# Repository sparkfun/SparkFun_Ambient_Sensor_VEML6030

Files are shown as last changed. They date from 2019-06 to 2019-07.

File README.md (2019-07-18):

SparkFun Ambient Light Sensor VEML6030 (Qwiic) 
========================================

SparkFun Ambient Light Sensor

[*SparkFun Ambient LIght Sensor - VEML6030 (Qwiic) (SEN-15436)*](https://www.sparkfun.com/products/15436)

The SparkFun Ambient Light Sensor - VEML6030 (Qwiic) is an I<sup>2</sup>C enabled
ambient light sensor with high sensitivity and high accuracy. It reads ambient
light in Lux and boasts a number of nice features including: the ability to set
high and low thresholds for an optional interrupt, power saving features that enable
single digit micro-amp current draw, and a readable  range from zero to 120,000 Lux. We've also written an Arduino 
library that gives full access to all features and includes example code demonstrating all its' abilities (see link below under **Documentation**). 

Repository Contents
-------------------

* **/Documentation** - Data sheets, additional product information
* **/Hardware** - Eagle design files (.brd, .sch)
* **/Libraries** - Libraries for use with the SparkFun Ambient Light Sensor.
* **/Production** - Production panel files (.brd)

Documentation
--------------
* **[SparkFun Ambient Light Sensor Arduino Library](https://github.com/sparkfun/SparkFun_Ambient_Light_Sensor_Arduino_Library)** - Arduino Library
* **[Hookup Guide](https://learn.sparkfun.com/tutorials/qwiic-ambient-light-sensor-veml6030-hookup-guide)** - Basic hookup guide for the SparkFun Ambient Light Sensor
* **[Qwiic Ecosystem](https://www.sparkfun.com/qwiic)** - Qwiic enabled for fast prototyping!

License Information
-------------------

This product is _**open source**_! 

Please review the LICENSE.md file for license information. 

If you have any questions or concerns on licensing, please contact technical support on our [SparkFun forums](https://forum.sparkfun.com/viewforum.php?f=152).

Distributed as-is; no warranty is given.

- Your friends at SparkFun.

_<COLLABORATION CREDIT>_

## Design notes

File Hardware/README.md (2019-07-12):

SparkFun Ambient Light Sensor VEML6030 Design Files
=====================================

The .sch and .brd files hare are Eagle CAD schematic and PCB design files from SparkFun Electronics.
A freeware version of Eagle can be found [here](http://www.cadsoftusa.com/download-eagle/freeware/).

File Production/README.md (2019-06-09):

SparkFun <PRODUCT NAME> Production Files
=========================================

These are the production files SparkFun uses for printing PCBs.

License Information
-------------------
This product is open source! 

The hardware is released under [Creative Commons ShareAlike 4.0 International](https://creativecommons.org/licenses/by-sa/4.0/).

Please use, reuse, and modify these files as you see fit. Please maintain attribution to SparkFun Electronics and release anything derivative under the same license.

Distributed as-is; no warranty is given.

- Your friends at SparkFun.

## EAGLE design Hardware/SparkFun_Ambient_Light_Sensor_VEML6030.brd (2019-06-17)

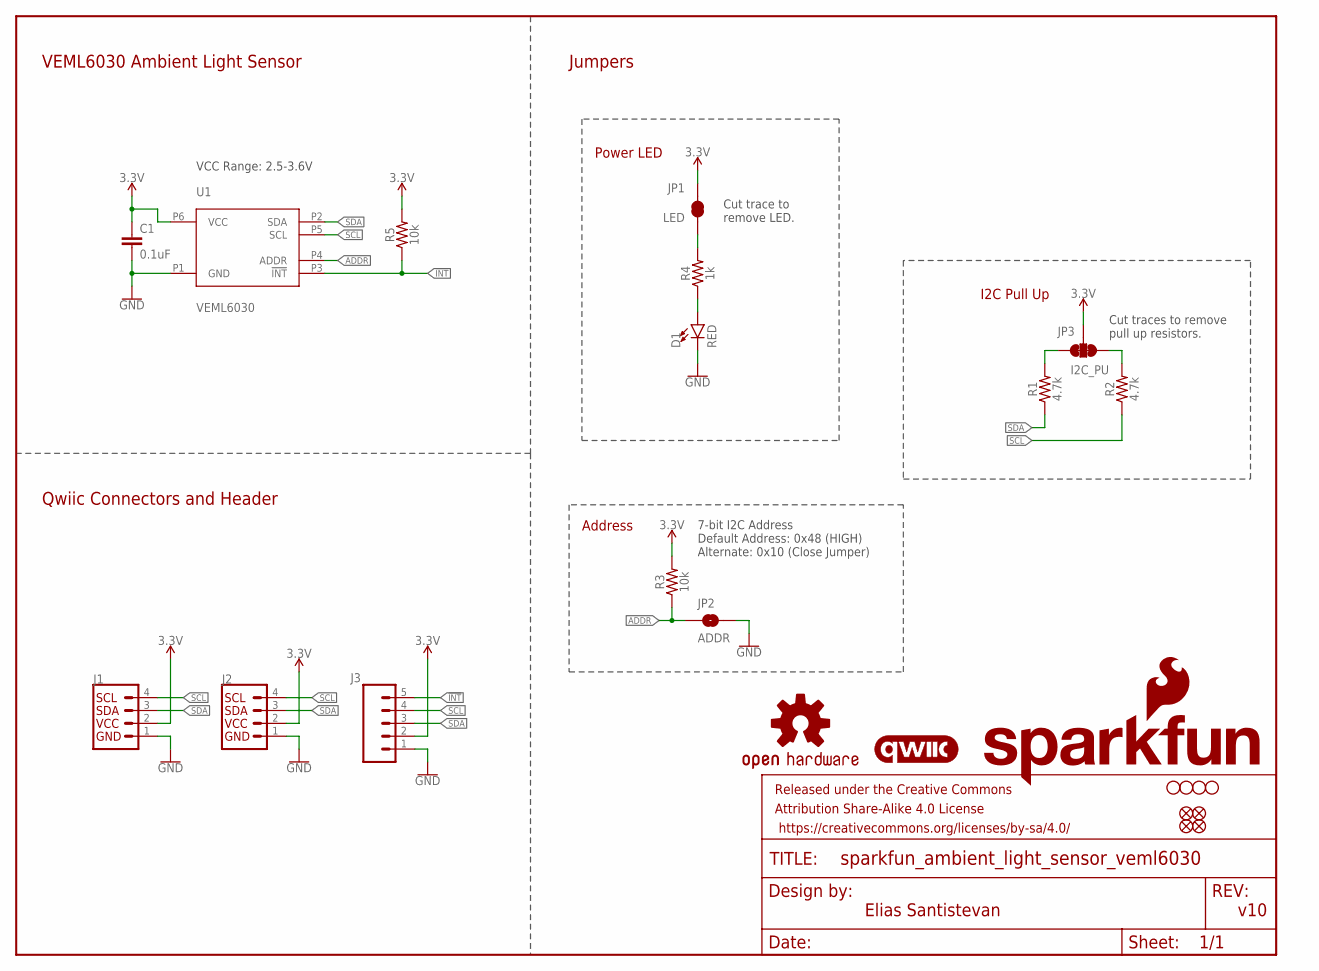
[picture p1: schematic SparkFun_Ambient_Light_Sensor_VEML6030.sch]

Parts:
C1: 0.1uF; 0603
D1: RED; LED-0603
FD1, FD2, FD3, FD4: FIDUCIAL1X2; FIDUCIAL-1X2
FRAME1: FRAME-LETTER; CREATIVE_COMMONS
H1, H2, H3, H4: STAND-OFFTIGHT; STAND-OFF-TIGHT
J1, J2: QWIIC_CONNECTORJS-1MM; JST04_1MM_RA
J3: CONN_05NO_SILK; 1X05_NO_SILK
JP1: LED; SMT-JUMPER_2_NC_TRACE_SILK
JP2: ADDR; SMT-JUMPER_2_NO_SILK
JP3: I2C_PU; SMT-JUMPER_3_2-NC_TRACE_SILK
LOGO1: SFE_LOGO_NAME_FLAME.1_INCH; SFE_LOGO_NAME_FLAME_.1
LOGO2: OSHW-LOGOS; OSHW-LOGO-S
R1, R2: 4.7k; 0603
R3, R5: 10k; 0603
R4: 1k; 0603
U1: VEML6030
U$1: QWIIC_LOGO_5MM; QWIIC_5MM

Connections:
3.3V: C1.1, J1.2, J2.2, J3.2, JP1.2, JP3.2, R3.2, R5.2, U1.P6 (VCC)
!INT: J3.5, R5.1, U1.P3 (!INT)
ADDR: JP2.1, R3.1, U1.P4 (ADDR)
GND: C1.2, D1.C, J1.1, J2.1, J3.1, JP2.2, U1.P1 (GND)
unnamed: D1.A, R4.1
unnamed: JP1.1, R4.2
unnamed: JP3.3, R1.2
unnamed: JP3.1, R2.2
SCL: J1.4, J2.4, J3.4, R2.1, U1.P5 (SCL)
SDA: J1.3, J2.3, J3.3, R1.1, U1.P2 (SDA)

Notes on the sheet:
v10
Elias Santistevan
Qwiic Connectors and Header
VEML6030 Ambient Light Sensor
Jumpers
Power LED
I2C Pull Up
Address
7-bit I2C Address Default Address: 0x48 (HIGH) Alternate: 0x10 (Close Jumper)
Cut trace to remove LED.
Cut traces to remove pull up resistors.
VCC Range: 2.5-3.6V

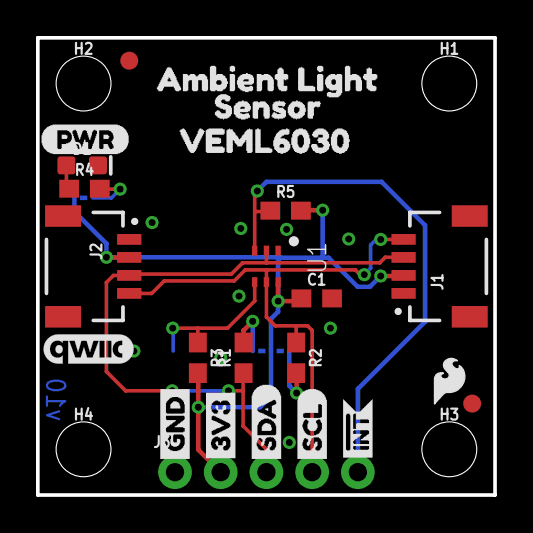
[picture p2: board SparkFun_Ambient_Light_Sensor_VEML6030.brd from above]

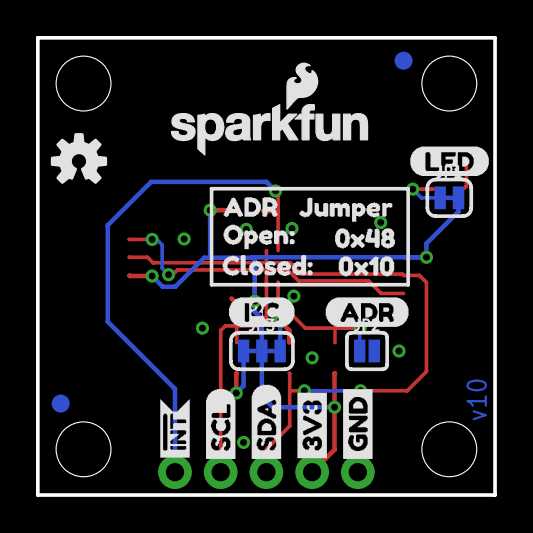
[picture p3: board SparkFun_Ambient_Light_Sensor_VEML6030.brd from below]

Board: 2 copper layers, 25.4 x 25.4 mm, 50 parts (21 on the bottom side), 10 nets.

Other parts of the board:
U$2, U$11: 3V3-04
U$3, U$8: GND-04
U$4, U$9: SDA-[)
U$5, U$10: SCL-[)
U$6, U$7: INT#-[<
U$12: I_SUPER2_C-()-04
U$13: ADR-()
U$14: LED0
U$15: AMBIENT_LIGHT0
U$16: SENSOR1
U$17: VEML60302
U$18: SFE_LOGO_FLAME_.1
U$19: PWR-()-04
U$20: CLOSED#2
U$21: OPEN#0
U$22: 0X481
U$24: 0X103
U$25: ADR0
U$26: JUMPER1

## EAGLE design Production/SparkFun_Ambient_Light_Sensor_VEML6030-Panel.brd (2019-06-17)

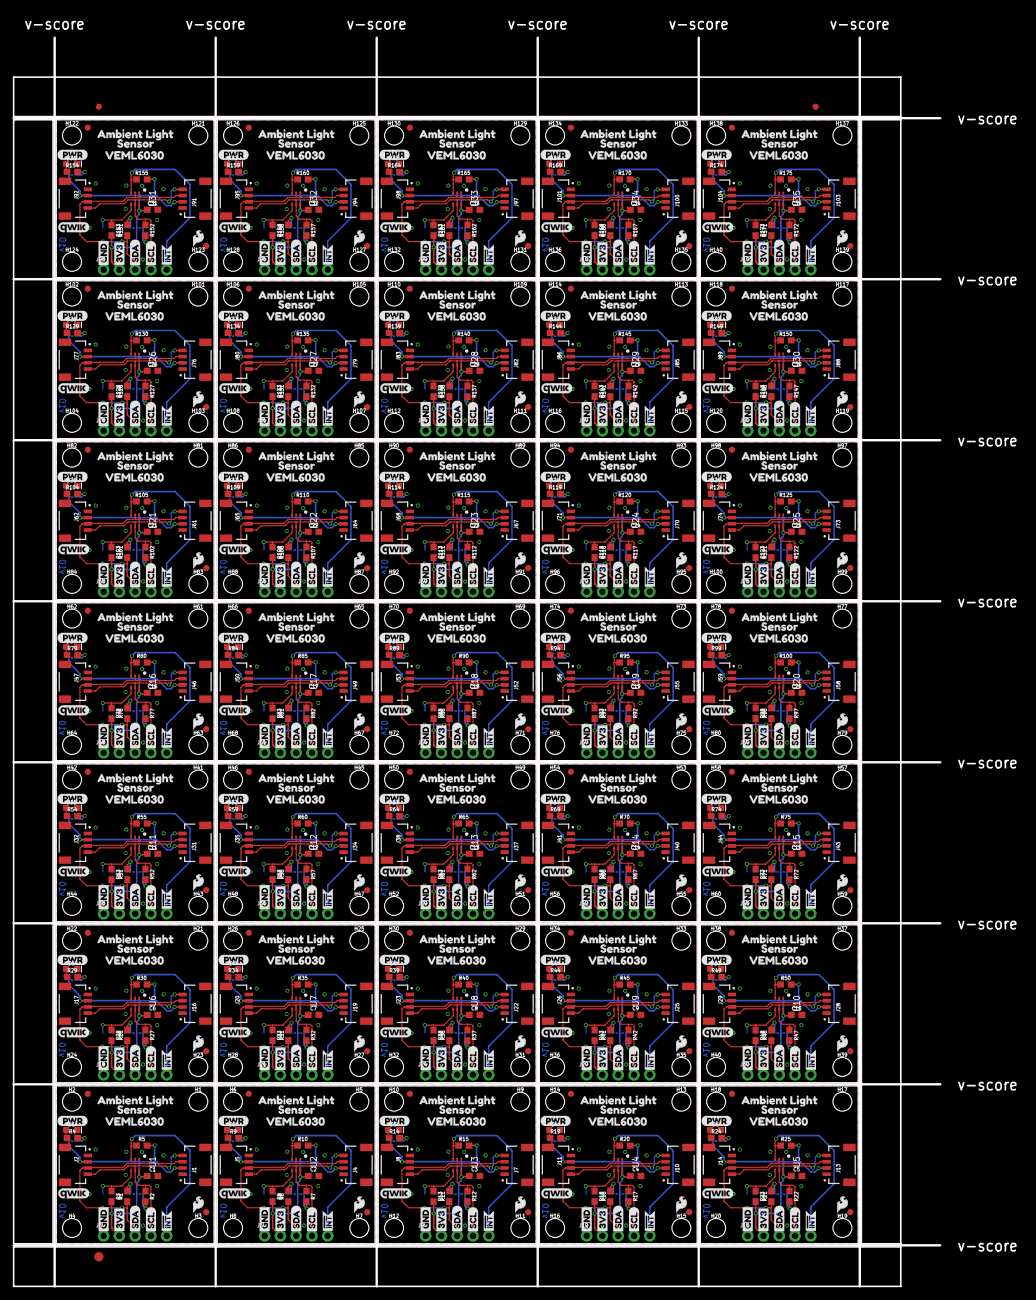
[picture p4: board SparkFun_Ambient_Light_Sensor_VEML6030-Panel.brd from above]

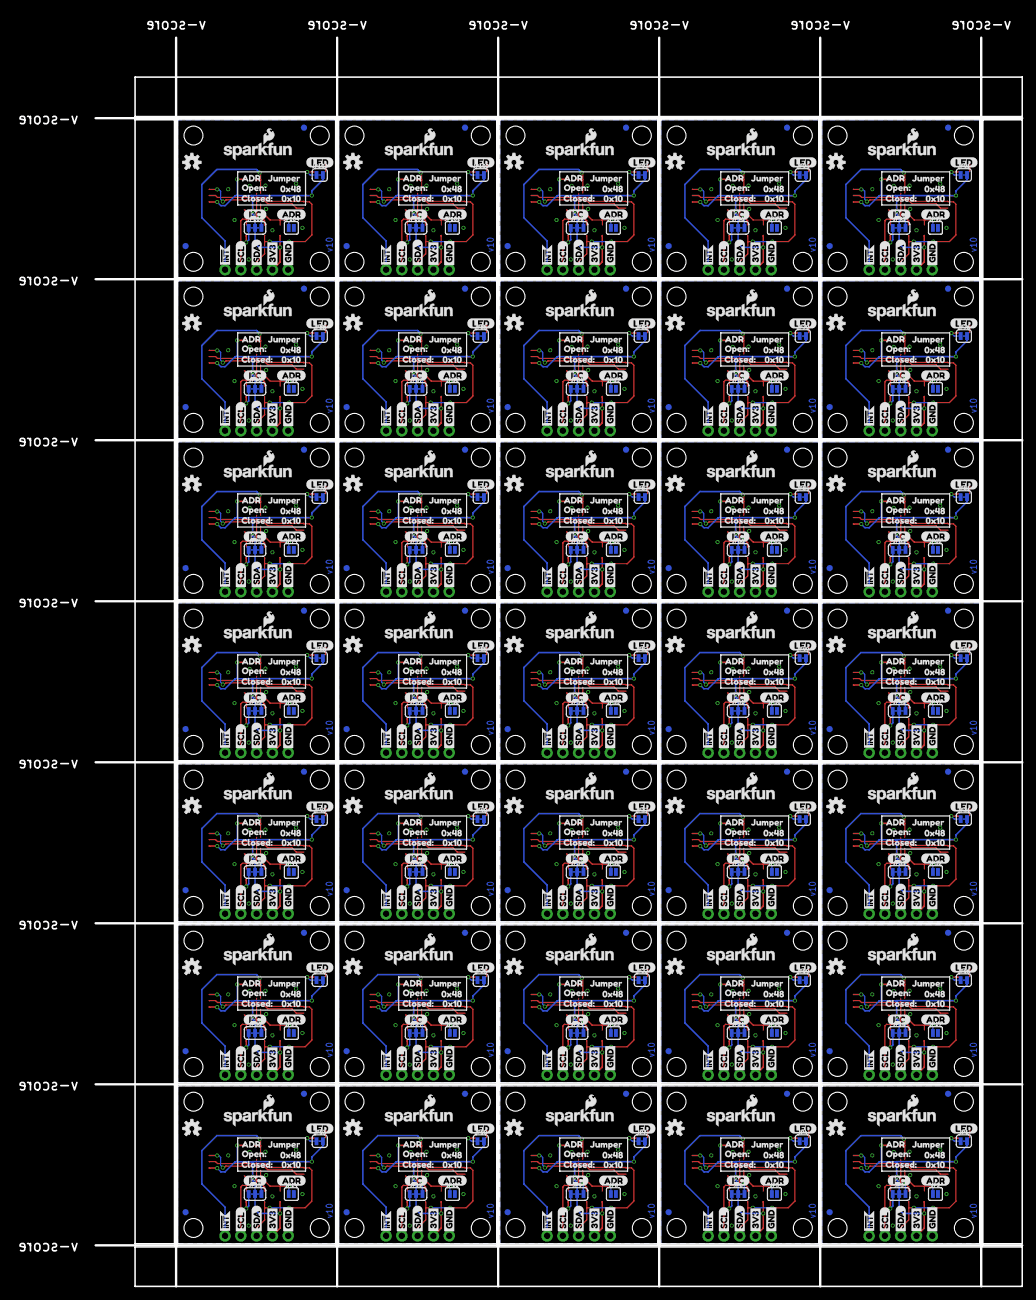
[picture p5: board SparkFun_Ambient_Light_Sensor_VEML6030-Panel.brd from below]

Board: 2 copper layers, 149.1 x 200.9 mm, 1718 parts (735 on the bottom side), 350 nets.

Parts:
C1, C2, C3, C4, C5, C6, C7, C8, C9, C10, C11, C12, C13, C14, C15, C16, C17, C18, C19, C20, C21, C22, C23, C24, C25, C26, C27, C28, C29, C30, C31, C32, C33, C34, C35: 0.1uF; 0603
D1, D2, D3, D4, D5, D6, D7, D8, D9, D10, D11, D12, D13, D14, D15, D16, D17, D18, D19, D20, D21, D22, D23, D24, D25, D26, D27, D28, D29, D30, D31, D32, D33, D34, D35: RED; LED-0603
E$1, E$2: FIDUCIAL-1X2
E$3: FIDUCIAL-1.5X3
FD1, FD2, FD3, FD4, FD5, FD6, FD7, FD8, FD9, FD10, FD11, FD12, FD13, FD14, FD15, FD16, FD17, FD18, FD19, FD20, FD21, FD22, FD23, FD24, FD25, FD26, FD27, FD28, FD29, FD30, FD31, FD32, FD33, FD34, FD35, FD36, FD37, FD38, FD39, FD40, FD41, FD42, FD43, FD44, FD45, FD46, FD47, FD48, FD49, FD50, FD51, FD52, FD53, FD54, FD55, FD56, FD57, FD58, FD59, FD60, FD61, FD62, FD63, FD64, FD65, FD66, FD67, FD68, FD69, FD70, FD71, FD72, FD73, FD74, FD75, FD76, FD77, FD78, FD79, FD80, FD81, FD82, FD83, FD84, FD85, FD86, FD87, FD88, FD89, FD90, FD91, FD92, FD93, FD94, FD95, FD96, FD97, FD98, FD99, FD100, FD101, FD102, FD103, FD104, FD105, FD106, FD107, FD108, FD109, FD110, FD111, FD112, FD113, FD114, FD115, FD116, FD117, FD118, FD119, FD120, FD121, FD122, FD123, FD124, FD125, FD126, FD127, FD128, FD129, FD130, FD131, FD132, FD133, FD134, FD135, FD136, FD137, FD138, FD139, FD140: FIDUCIAL1X2; FIDUCIAL-1X2
H1, H2, H3, H4, H5, H6, H7, H8, H9, H10, H11, H12, H13, H14, H15, H16, H17, H18, H19, H20, H21, H22, H23, H24, H25, H26, H27, H28, H29, H30, H31, H32, H33, H34, H35, H36, H37, H38, H39, H40, H41, H42, H43, H44, H45, H46, H47, H48, H49, H50, H51, H52, H53, H54, H55, H56, H57, H58, H59, H60, H61, H62, H63, H64, H65, H66, H67, H68, H69, H70, H71, H72, H73, H74, H75, H76, H77, H78, H79, H80, H81, H82, H83, H84, H85, H86, H87, H88, H89, H90, H91, H92, H93, H94, H95, H96, H97, H98, H99, H100, H101, H102, H103, H104, H105, H106, H107, H108, H109, H110, H111, H112, H113, H114, H115, H116, H117, H118, H119, H120, H121, H122, H123, H124, H125, H126, H127, H128, H129, H130, H131, H132, H133, H134, H135, H136, H137, H138, H139, H140: STAND-OFFTIGHT; STAND-OFF-TIGHT
J1, J2, J4, J5, J7, J8, J10, J11, J13, J14, J16, J17, J19, J20, J22, J23, J25, J26, J28, J29, J31, J32, J34, J35, J37, J38, J40, J41, J43, J44, J46, J47, J49, J50, J52, J53, J55, J56, J58, J59, J61, J62, J64, J65, J67, J68, J70, J71, J73, J74, J76, J77, J79, J80, J82, J83, J85, J86, J88, J89, J91, J92, J94, J95, J97, J98, J100, J101, J103, J104: JST04_1MM_RA
J3, J6, J9, J12, J15, J18, J21, J24, J27, J30, J33, J36, J39, J42, J45, J48, J51, J54, J57, J60, J63, J66, J69, J72, J75, J78, J81, J84, J87, J90, J93, J96, J99, J102, J105: 1X05_NO_SILK
JP1, JP4, JP7, JP10, JP13, JP16, JP19, JP22, JP25, JP28, JP31, JP34, JP37, JP40, JP43, JP46, JP49, JP52, JP55, JP58, JP61, JP64, JP67, JP70, JP73, JP76, JP79, JP82, JP85, JP88, JP91, JP94, JP97, JP100, JP103: LED; SMT-JUMPER_2_NC_TRACE_SILK
JP2, JP5, JP8, JP11, JP14, JP17, JP20, JP23, JP26, JP29, JP32, JP35, JP38, JP41, JP44, JP47, JP50, JP53, JP56, JP59, JP62, JP65, JP68, JP71, JP74, JP77, JP80, JP83, JP86, JP89, JP92, JP95, JP98, JP101, JP104: ADDR; SMT-JUMPER_2_NO_SILK
JP3, JP6, JP9, JP12, JP15, JP18, JP21, JP24, JP27, JP30, JP33, JP36, JP39, JP42, JP45, JP48, JP51, JP54, JP57, JP60, JP63, JP66, JP69, JP72, JP75, JP78, JP81, JP84, JP87, JP90, JP93, JP96, JP99, JP102, JP105: I2C_PU; SMT-JUMPER_3_2-NC_TRACE_SILK
LOGO1, LOGO3, LOGO5, LOGO7, LOGO9, LOGO11, LOGO13, LOGO15, LOGO17, LOGO19, LOGO21, LOGO23, LOGO25, LOGO27, LOGO29, LOGO31, LOGO33, LOGO35, LOGO37, LOGO39, LOGO41, LOGO43, LOGO45, LOGO47, LOGO49, LOGO51, LOGO53, LOGO55, LOGO57, LOGO59, LOGO61, LOGO63, LOGO65, LOGO67, LOGO69: SFE_LOGO_NAME_FLAME.1_INCH; SFE_LOGO_NAME_FLAME_.1
LOGO2, LOGO4, LOGO6, LOGO8, LOGO10, LOGO12, LOGO14, LOGO16, LOGO18, LOGO20, LOGO22, LOGO24, LOGO26, LOGO28, LOGO30, LOGO32, LOGO34, LOGO36, LOGO38, LOGO40, LOGO42, LOGO44, LOGO46, LOGO48, LOGO50, LOGO52, LOGO54, LOGO56, LOGO58, LOGO60, LOGO62, LOGO64, LOGO66, LOGO68, LOGO70: OSHW-LOGOS; OSHW-LOGO-S
R1, R2, R6, R7, R11, R12, R16, R17, R21, R22, R26, R27, R31, R32, R36, R37, R41, R42, R46, R47, R51, R52, R56, R57, R61, R62, R66, R67, R71, R72, R76, R77, R81, R82, R86, R87, R91, R92, R96, R97, R101, R102, R106, R107, R111, R112, R116, R117, R121, R122, R126, R127, R131, R132, R136, R137, R141, R142, R146, R147, R151, R152, R156, R157, R161, R162, R166, R167, R171, R172: 4.7k; 0603
R3, R5, R8, R10, R13, R15, R18, R20, R23, R25, R28, R30, R33, R35, R38, R40, R43, R45, R48, R50, R53, R55, R58, R60, R63, R65, R68, R70, R73, R75, R78, R80, R83, R85, R88, R90, R93, R95, R98, R100, R103, R105, R108, R110, R113, R115, R118, R120, R123, R125, R128, R130, R133, R135, R138, R140, R143, R145, R148, R150, R153, R155, R158, R160, R163, R165, R168, R170, R173, R175: 10k; 0603
R4, R9, R14, R19, R24, R29, R34, R39, R44, R49, R54, R59, R64, R69, R74, R79, R84, R89, R94, R99, R104, R109, R114, R119, R124, R129, R134, R139, R144, R149, R154, R159, R164, R169, R174: 1k; 0603
U1, U2, U3, U4, U5, U6, U7, U8, U9, U10, U11, U12, U13, U14, U15, U16, U17, U18, U19, U20, U21, U22, U23, U24, U25, U26, U27, U28, U29, U30, U31, U32, U33, U34, U35: VEML6030
U$1, U$23, U$51, U$76, U$101, U$126, U$151, U$176, U$201, U$226, U$251, U$276, U$301, U$326, U$351, U$376, U$401, U$426, U$451, U$476, U$501, U$526, U$551, U$576, U$601, U$626, U$651, U$676, U$701, U$726, U$751, U$776, U$801, U$826, U$851: QWIIC_LOGO_5MM; QWIIC_5MM
U$2, U$11, U$27, U$36, U$52, U$61, U$77, U$86, U$102, U$111, U$127, U$136, U$152, U$161, U$177, U$186, U$202, U$211, U$227, U$236, U$252, U$261, U$277, U$286, U$302, U$311, U$327, U$336, U$352, U$361, U$377, U$386, U$402, U$411, U$427, U$436, U$452, U$461, U$477, U$486, U$502, U$511, U$527, U$536, U$552, U$561, U$577, U$586, U$602, U$611, U$627, U$636, U$652, U$661, U$677, U$686, U$702, U$711, U$727, U$736, U$752, U$761, U$777, U$786, U$802, U$811, U$827, U$836, U$852, U$861: 3V3-04
U$3, U$8, U$28, U$33, U$53, U$58, U$78, U$83, U$103, U$108, U$128, U$133, U$153, U$158, U$178, U$183, U$203, U$208, U$228, U$233, U$253, U$258, U$278, U$283, U$303, U$308, U$328, U$333, U$353, U$358, U$378, U$383, U$403, U$408, U$428, U$433, U$453, U$458, U$478, U$483, U$503, U$508, U$528, U$533, U$553, U$558, U$578, U$583, U$603, U$608, U$628, U$633, U$653, U$658, U$678, U$683, U$703, U$708, U$728, U$733, U$753, U$758, U$778, U$783, U$803, U$808, U$828, U$833, U$853, U$858: GND-04
U$4, U$9, U$29, U$34, U$54, U$59, U$79, U$84, U$104, U$109, U$129, U$134, U$154, U$159, U$179, U$184, U$204, U$209, U$229, U$234, U$254, U$259, U$279, U$284, U$304, U$309, U$329, U$334, U$354, U$359, U$379, U$384, U$404, U$409, U$429, U$434, U$454, U$459, U$479, U$484, U$504, U$509, U$529, U$534, U$554, U$559, U$579, U$584, U$604, U$609, U$629, U$634, U$654, U$659, U$679, U$684, U$704, U$709, U$729, U$734, U$754, U$759, U$779, U$784, U$804, U$809, U$829, U$834, U$854, U$859: SDA-[)
U$5, U$10, U$30, U$35, U$55, U$60, U$80, U$85, U$105, U$110, U$130, U$135, U$155, U$160, U$180, U$185, U$205, U$210, U$230, U$235, U$255, U$260, U$280, U$285, U$305, U$310, U$330, U$335, U$355, U$360, U$380, U$385, U$405, U$410, U$430, U$435, U$455, U$460, U$480, U$485, U$505, U$510, U$530, U$535, U$555, U$560, U$580, U$585, U$605, U$610, U$630, U$635, U$655, U$660, U$680, U$685, U$705, U$710, U$730, U$735, U$755, U$760, U$780, U$785, U$805, U$810, U$830, U$835, U$855, U$860: SCL-[)
U$6, U$7, U$31, U$32, U$56, U$57, U$81, U$82, U$106, U$107, U$131, U$132, U$156, U$157, U$181, U$182, U$206, U$207, U$231, U$232, U$256, U$257, U$281, U$282, U$306, U$307, U$331, U$332, U$356, U$357, U$381, U$382, U$406, U$407, U$431, U$432, U$456, U$457, U$481, U$482, U$506, U$507, U$531, U$532, U$556, U$557, U$581, U$582, U$606, U$607, U$631, U$632, U$656, U$657, U$681, U$682, U$706, U$707, U$731, U$732, U$756, U$757, U$781, U$782, U$806, U$807, U$831, U$832, U$856, U$857: INT#-[<
U$12, U$37, U$62, U$87, U$112, U$137, U$162, U$187, U$212, U$237, U$262, U$287, U$312, U$337, U$362, U$387, U$412, U$437, U$462, U$487, U$512, U$537, U$562, U$587, U$612, U$637, U$662, U$687, U$712, U$737, U$762, U$787, U$812, U$837, U$862: I_SUPER2_C-()-04
U$13, U$38, U$63, U$88, U$113, U$138, U$163, U$188, U$213, U$238, U$263, U$288, U$313, U$338, U$363, U$388, U$413, U$438, U$463, U$488, U$513, U$538, U$563, U$588, U$613, U$638, U$663, U$688, U$713, U$738, U$763, U$788, U$813, U$838, U$863: ADR-()
U$14, U$39, U$64, U$89, U$114, U$139, U$164, U$189, U$214, U$239, U$264, U$289, U$314, U$339, U$364, U$389, U$414, U$439, U$464, U$489, U$514, U$539, U$564, U$589, U$614, U$639, U$664, U$689, U$714, U$739, U$764, U$789, U$814, U$839, U$864: LED0
U$15, U$40, U$65, U$90, U$115, U$140, U$165, U$190, U$215, U$240, U$265, U$290, U$315, U$340, U$365, U$390, U$415, U$440, U$465, U$490, U$515, U$540, U$565, U$590, U$615, U$640, U$665, U$690, U$715, U$740, U$765, U$790, U$815, U$840, U$865: AMBIENT_LIGHT0
U$16, U$41, U$66, U$91, U$116, U$141, U$166, U$191, U$216, U$241, U$266, U$291, U$316, U$341, U$366, U$391, U$416, U$441, U$466, U$491, U$516, U$541, U$566, U$591, U$616, U$641, U$666, U$691, U$716, U$741, U$766, U$791, U$816, U$841, U$866: SENSOR1
U$17, U$42, U$67, U$92, U$117, U$142, U$167, U$192, U$217, U$242, U$267, U$292, U$317, U$342, U$367, U$392, U$417, U$442, U$467, U$492, U$517, U$542, U$567, U$592, U$617, U$642, U$667, U$692, U$717, U$742, U$767, U$792, U$817, U$842, U$867: VEML60302
U$18, U$43, U$68, U$93, U$118, U$143, U$168, U$193, U$218, U$243, U$268, U$293, U$318, U$343, U$368, U$393, U$418, U$443, U$468, U$493, U$518, U$543, U$568, U$593, U$618, U$643, U$668, U$693, U$718, U$743, U$768, U$793, U$818, U$843, U$868: SFE_LOGO_FLAME_.1
U$19, U$44, U$69, U$94, U$119, U$144, U$169, U$194, U$219, U$244, U$269, U$294, U$319, U$344, U$369, U$394, U$419, U$444, U$469, U$494, U$519, U$544, U$569, U$594, U$619, U$644, U$669, U$694, U$719, U$744, U$769, U$794, U$819, U$844, U$869: PWR-()-04
U$20, U$49, U$74, U$99, U$124, U$149, U$174, U$199, U$224, U$249, U$274, U$299, U$324, U$349, U$374, U$399, U$424, U$449, U$474, U$499, U$524, U$549, U$574, U$599, U$624, U$649, U$674, U$699, U$724, U$749, U$774, U$799, U$824, U$849, U$874: CLOSED#2
U$21, U$50, U$75, U$100, U$125, U$150, U$175, U$200, U$225, U$250, U$275, U$300, U$325, U$350, U$375, U$400, U$425, U$450, U$475, U$500, U$525, U$550, U$575, U$600, U$625, U$650, U$675, U$700, U$725, U$750, U$775, U$800, U$825, U$850, U$875: OPEN#0
U$22, U$45, U$70, U$95, U$120, U$145, U$170, U$195, U$220, U$245, U$270, U$295, U$320, U$345, U$370, U$395, U$420, U$445, U$470, U$495, U$520, U$545, U$570, U$595, U$620, U$645, U$670, U$695, U$720, U$745, U$770, U$795, U$820, U$845, U$870: 0X481
U$24, U$46, U$71, U$96, U$121, U$146, U$171, U$196, U$221, U$246, U$271, U$296, U$321, U$346, U$371, U$396, U$421, U$446, U$471, U$496, U$521, U$546, U$571, U$596, U$621, U$646, U$671, U$696, U$721, U$746, U$771, U$796, U$821, U$846, U$871: 0X103
U$25, U$47, U$72, U$97, U$122, U$147, U$172, U$197, U$222, U$247, U$272, U$297, U$322, U$347, U$372, U$397, U$422, U$447, U$472, U$497, U$522, U$547, U$572, U$597, U$622, U$647, U$672, U$697, U$722, U$747, U$772, U$797, U$822, U$847, U$872: ADR0
U$26, U$48, U$73, U$98, U$123, U$148, U$173, U$198, U$223, U$248, U$273, U$298, U$323, U$348, U$373, U$398, U$423, U$448, U$473, U$498, U$523, U$548, U$573, U$598, U$623, U$648, U$673, U$698, U$723, U$748, U$773, U$798, U$823, U$848, U$873: JUMPER1

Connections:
3.3V: C1.1, J1.2, J2.2, J3.2, JP1.2, JP3.2, R3.2, R5.2, U1.P6
3.3V1: C2.1, J4.2, J5.2, J6.2, JP4.2, JP6.2, R8.2, R10.2, U2.P6
3.3V2: C3.1, J7.2, J8.2, J9.2, JP7.2, JP9.2, R13.2, R15.2, U3.P6
3.3V3: C4.1, J10.2, J11.2, J12.2, JP10.2, JP12.2, R18.2, R20.2, U4.P6
3.3V4: C5.1, J13.2, J14.2, J15.2, JP13.2, JP15.2, R23.2, R25.2, U5.P6
3.3V5: C6.1, J16.2, J17.2, J18.2, JP16.2, JP18.2, R28.2, R30.2, U6.P6
3.3V6: C7.1, J19.2, J20.2, J21.2, JP19.2, JP21.2, R33.2, R35.2, U7.P6
3.3V7: C8.1, J22.2, J23.2, J24.2, JP22.2, JP24.2, R38.2, R40.2, U8.P6
3.3V8: C9.1, J25.2, J26.2, J27.2, JP25.2, JP27.2, R43.2, R45.2, U9.P6
3.3V9: C10.1, J28.2, J29.2, J30.2, JP28.2, JP30.2, R48.2, R50.2, U10.P6
3.3V10: C11.1, J31.2, J32.2, J33.2, JP31.2, JP33.2, R53.2, R55.2, U11.P6
3.3V11: C12.1, J34.2, J35.2, J36.2, JP34.2, JP36.2, R58.2, R60.2, U12.P6
3.3V12: C13.1, J37.2, J38.2, J39.2, JP37.2, JP39.2, R63.2, R65.2, U13.P6
3.3V13: C14.1, J40.2, J41.2, J42.2, JP40.2, JP42.2, R68.2, R70.2, U14.P6
3.3V14: C15.1, J43.2, J44.2, J45.2, JP43.2, JP45.2, R73.2, R75.2, U15.P6
3.3V15: C16.1, J46.2, J47.2, J48.2, JP46.2, JP48.2, R78.2, R80.2, U16.P6
3.3V16: C17.1, J49.2, J50.2, J51.2, JP49.2, JP51.2, R83.2, R85.2, U17.P6
3.3V17: C18.1, J52.2, J53.2, J54.2, JP52.2, JP54.2, R88.2, R90.2, U18.P6
3.3V18: C19.1, J55.2, J56.2, J57.2, JP55.2, JP57.2, R93.2, R95.2, U19.P6
3.3V19: C20.1, J58.2, J59.2, J60.2, JP58.2, JP60.2, R98.2, R100.2, U20.P6
3.3V20: C21.1, J61.2, J62.2, J63.2, JP61.2, JP63.2, R103.2, R105.2, U21.P6
3.3V21: C22.1, J64.2, J65.2, J66.2, JP64.2, JP66.2, R108.2, R110.2, U22.P6
3.3V22: C23.1, J67.2, J68.2, J69.2, JP67.2, JP69.2, R113.2, R115.2, U23.P6
3.3V23: C24.1, J70.2, J71.2, J72.2, JP70.2, JP72.2, R118.2, R120.2, U24.P6
3.3V24: C25.1, J73.2, J74.2, J75.2, JP73.2, JP75.2, R123.2, R125.2, U25.P6
3.3V25: C26.1, J76.2, J77.2, J78.2, JP76.2, JP78.2, R128.2, R130.2, U26.P6
3.3V26: C27.1, J79.2, J80.2, J81.2, JP79.2, JP81.2, R133.2, R135.2, U27.P6
3.3V27: C28.1, J82.2, J83.2, J84.2, JP82.2, JP84.2, R138.2, R140.2, U28.P6
3.3V28: C29.1, J85.2, J86.2, J87.2, JP85.2, JP87.2, R143.2, R145.2, U29.P6
3.3V29: C30.1, J88.2, J89.2, J90.2, JP88.2, JP90.2, R148.2, R150.2, U30.P6
3.3V30: C31.1, J91.2, J92.2, J93.2, JP91.2, JP93.2, R153.2, R155.2, U31.P6
3.3V31: C32.1, J94.2, J95.2, J96.2, JP94.2, JP96.2, R158.2, R160.2, U32.P6
3.3V32: C33.1, J97.2, J98.2, J99.2, JP97.2, JP99.2, R163.2, R165.2, U33.P6
3.3V33: C34.1, J100.2, J101.2, J102.2, JP100.2, JP102.2, R168.2, R170.2, U34.P6
3.3V34: C35.1, J103.2, J104.2, J105.2, JP103.2, JP105.2, R173.2, R175.2, U35.P6
!INT: J3.5, R5.1, U1.P3
!INT1: J6.5, R10.1, U2.P3
!INT2: J9.5, R15.1, U3.P3
!INT3: J12.5, R20.1, U4.P3
!INT4: J15.5, R25.1, U5.P3
!INT5: J18.5, R30.1, U6.P3
!INT6: J21.5, R35.1, U7.P3
!INT7: J24.5, R40.1, U8.P3
!INT8: J27.5, R45.1, U9.P3
!INT9: J30.5, R50.1, U10.P3
!INT10: J33.5, R55.1, U11.P3
!INT11: J36.5, R60.1, U12.P3
!INT12: J39.5, R65.1, U13.P3
!INT13: J42.5, R70.1, U14.P3
!INT14: J45.5, R75.1, U15.P3
!INT15: J48.5, R80.1, U16.P3
!INT16: J51.5, R85.1, U17.P3
!INT17: J54.5, R90.1, U18.P3
!INT18: J57.5, R95.1, U19.P3
!INT19: J60.5, R100.1, U20.P3
!INT20: J63.5, R105.1, U21.P3
!INT21: J66.5, R110.1, U22.P3
!INT22: J69.5, R115.1, U23.P3
!INT23: J72.5, R120.1, U24.P3
!INT24: J75.5, R125.1, U25.P3
!INT25: J78.5, R130.1, U26.P3
!INT26: J81.5, R135.1, U27.P3
!INT27: J84.5, R140.1, U28.P3
!INT28: J87.5, R145.1, U29.P3
!INT29: J90.5, R150.1, U30.P3
!INT30: J93.5, R155.1, U31.P3
!INT31: J96.5, R160.1, U32.P3
!INT32: J99.5, R165.1, U33.P3
!INT33: J102.5, R170.1, U34.P3
!INT34: J105.5, R175.1, U35.P3
ADDR: JP2.1, R3.1, U1.P4
ADDR1: JP5.1, R8.1, U2.P4
ADDR2: JP8.1, R13.1, U3.P4
ADDR3: JP11.1, R18.1, U4.P4
ADDR4: JP14.1, R23.1, U5.P4
ADDR5: JP17.1, R28.1, U6.P4
ADDR6: JP20.1, R33.1, U7.P4
ADDR7: JP23.1, R38.1, U8.P4
ADDR8: JP26.1, R43.1, U9.P4
ADDR9: JP29.1, R48.1, U10.P4
ADDR10: JP32.1, R53.1, U11.P4
ADDR11: JP35.1, R58.1, U12.P4
ADDR12: JP38.1, R63.1, U13.P4
ADDR13: JP41.1, R68.1, U14.P4
ADDR14: JP44.1, R73.1, U15.P4
ADDR15: JP47.1, R78.1, U16.P4
ADDR16: JP50.1, R83.1, U17.P4
ADDR17: JP53.1, R88.1, U18.P4
ADDR18: JP56.1, R93.1, U19.P4
ADDR19: JP59.1, R98.1, U20.P4
ADDR20: JP62.1, R103.1, U21.P4
ADDR21: JP65.1, R108.1, U22.P4
ADDR22: JP68.1, R113.1, U23.P4
ADDR23: JP71.1, R118.1, U24.P4
ADDR24: JP74.1, R123.1, U25.P4
ADDR25: JP77.1, R128.1, U26.P4
ADDR26: JP80.1, R133.1, U27.P4
ADDR27: JP83.1, R138.1, U28.P4
ADDR28: JP86.1, R143.1, U29.P4
ADDR29: JP89.1, R148.1, U30.P4
ADDR30: JP92.1, R153.1, U31.P4
ADDR31: JP95.1, R158.1, U32.P4
ADDR32: JP98.1, R163.1, U33.P4
ADDR33: JP101.1, R168.1, U34.P4
ADDR34: JP104.1, R173.1, U35.P4
GND: C1.2, D1.C, J1.1, J2.1, J3.1, JP2.2, U1.P1
GND1: C2.2, D2.C, J4.1, J5.1, J6.1, JP5.2, U2.P1
GND2: C3.2, D3.C, J7.1, J8.1, J9.1, JP8.2, U3.P1
GND3: C4.2, D4.C, J10.1, J11.1, J12.1, JP11.2, U4.P1
GND4: C5.2, D5.C, J13.1, J14.1, J15.1, JP14.2, U5.P1
GND5: C6.2, D6.C, J16.1, J17.1, J18.1, JP17.2, U6.P1
GND6: C7.2, D7.C, J19.1, J20.1, J21.1, JP20.2, U7.P1
GND7: C8.2, D8.C, J22.1, J23.1, J24.1, JP23.2, U8.P1
GND8: C9.2, D9.C, J25.1, J26.1, J27.1, JP26.2, U9.P1
GND9: C10.2, D10.C, J28.1, J29.1, J30.1, JP29.2, U10.P1
GND10: C11.2, D11.C, J31.1, J32.1, J33.1, JP32.2, U11.P1
GND11: C12.2, D12.C, J34.1, J35.1, J36.1, JP35.2, U12.P1
GND12: C13.2, D13.C, J37.1, J38.1, J39.1, JP38.2, U13.P1
GND13: C14.2, D14.C, J40.1, J41.1, J42.1, JP41.2, U14.P1
GND14: C15.2, D15.C, J43.1, J44.1, J45.1, JP44.2, U15.P1
GND15: C16.2, D16.C, J46.1, J47.1, J48.1, JP47.2, U16.P1
GND16: C17.2, D17.C, J49.1, J50.1, J51.1, JP50.2, U17.P1
GND17: C18.2, D18.C, J52.1, J53.1, J54.1, JP53.2, U18.P1
GND18: C19.2, D19.C, J55.1, J56.1, J57.1, JP56.2, U19.P1
GND19: C20.2, D20.C, J58.1, J59.1, J60.1, JP59.2, U20.P1
GND20: C21.2, D21.C, J61.1, J62.1, J63.1, JP62.2, U21.P1
GND21: C22.2, D22.C, J64.1, J65.1, J66.1, JP65.2, U22.P1
GND22: C23.2, D23.C, J67.1, J68.1, J69.1, JP68.2, U23.P1
GND23: C24.2, D24.C, J70.1, J71.1, J72.1, JP71.2, U24.P1
GND24: C25.2, D25.C, J73.1, J74.1, J75.1, JP74.2, U25.P1
GND25: C26.2, D26.C, J76.1, J77.1, J78.1, JP77.2, U26.P1
GND26: C27.2, D27.C, J79.1, J80.1, J81.1, JP80.2, U27.P1
GND27: C28.2, D28.C, J82.1, J83.1, J84.1, JP83.2, U28.P1
GND28: C29.2, D29.C, J85.1, J86.1, J87.1, JP86.2, U29.P1
GND29: C30.2, D30.C, J88.1, J89.1, J90.1, JP89.2, U30.P1
GND30: C31.2, D31.C, J91.1, J92.1, J93.1, JP92.2, U31.P1
GND31: C32.2, D32.C, J94.1, J95.1, J96.1, JP95.2, U32.P1
GND32: C33.2, D33.C, J97.1, J98.1, J99.1, JP98.2, U33.P1
GND33: C34.2, D34.C, J100.1, J101.1, J102.1, JP101.2, U34.P1
GND34: C35.2, D35.C, J103.1, J104.1, J105.1, JP104.2, U35.P1
unnamed: D1.A, R4.1
unnamed: JP1.1, R4.2
unnamed: JP3.3, R1.2
unnamed: JP3.1, R2.2
unnamed: D2.A, R9.1
unnamed: JP4.1, R9.2
unnamed: JP6.3, R6.2
unnamed: JP6.1, R7.2
unnamed: D3.A, R14.1
unnamed: JP7.1, R14.2
unnamed: JP9.3, R11.2
unnamed: JP9.1, R12.2
unnamed: D4.A, R19.1
unnamed: JP10.1, R19.2
unnamed: JP12.3, R16.2
unnamed: JP12.1, R17.2
unnamed: D5.A, R24.1
unnamed: JP13.1, R24.2
unnamed: JP15.3, R21.2
unnamed: JP15.1, R22.2
unnamed: D6.A, R29.1
unnamed: JP16.1, R29.2
unnamed: JP18.3, R26.2
unnamed: JP18.1, R27.2
unnamed: D7.A, R34.1
unnamed: JP19.1, R34.2
unnamed: JP21.3, R31.2
unnamed: JP21.1, R32.2
unnamed: D8.A, R39.1
unnamed: JP22.1, R39.2
unnamed: JP24.3, R36.2
unnamed: JP24.1, R37.2
unnamed: D9.A, R44.1
unnamed: JP25.1, R44.2
unnamed: JP27.3, R41.2
unnamed: JP27.1, R42.2
unnamed: D10.A, R49.1
unnamed: JP28.1, R49.2
unnamed: JP30.3, R46.2
unnamed: JP30.1, R47.2
unnamed: D11.A, R54.1
unnamed: JP31.1, R54.2
unnamed: JP33.3, R51.2
unnamed: JP33.1, R52.2
unnamed: D12.A, R59.1
unnamed: JP34.1, R59.2
unnamed: JP36.3, R56.2
unnamed: JP36.1, R57.2
unnamed: D13.A, R64.1
unnamed: JP37.1, R64.2
unnamed: JP39.3, R61.2
unnamed: JP39.1, R62.2
unnamed: D14.A, R69.1
unnamed: JP40.1, R69.2
unnamed: JP42.3, R66.2
unnamed: JP42.1, R67.2
unnamed: D15.A, R74.1
unnamed: JP43.1, R74.2
unnamed: JP45.3, R71.2
unnamed: JP45.1, R72.2
unnamed: D16.A, R79.1
unnamed: JP46.1, R79.2
unnamed: JP48.3, R76.2
unnamed: JP48.1, R77.2
unnamed: D17.A, R84.1
unnamed: JP49.1, R84.2
unnamed: JP51.3, R81.2
unnamed: JP51.1, R82.2
unnamed: D18.A, R89.1
unnamed: JP52.1, R89.2
unnamed: JP54.3, R86.2
unnamed: JP54.1, R87.2
unnamed: D19.A, R94.1
unnamed: JP55.1, R94.2
unnamed: JP57.3, R91.2
unnamed: JP57.1, R92.2
unnamed: D20.A, R99.1
unnamed: JP58.1, R99.2
unnamed: JP60.3, R96.2
unnamed: JP60.1, R97.2
unnamed: D21.A, R104.1
unnamed: JP61.1, R104.2
unnamed: JP63.3, R101.2
unnamed: JP63.1, R102.2
unnamed: D22.A, R109.1
unnamed: JP64.1, R109.2
unnamed: JP66.3, R106.2
unnamed: JP66.1, R107.2
unnamed: D23.A, R114.1
unnamed: JP67.1, R114.2
unnamed: JP69.3, R111.2
unnamed: JP69.1, R112.2
unnamed: D24.A, R119.1
unnamed: JP70.1, R119.2
unnamed: JP72.3, R116.2
unnamed: JP72.1, R117.2
unnamed: D25.A, R124.1
unnamed: JP73.1, R124.2
unnamed: JP75.3, R121.2
unnamed: JP75.1, R122.2
unnamed: D26.A, R129.1
unnamed: JP76.1, R129.2
unnamed: JP78.3, R126.2
unnamed: JP78.1, R127.2
unnamed: D27.A, R134.1
unnamed: JP79.1, R134.2
unnamed: JP81.3, R131.2
unnamed: JP81.1, R132.2
unnamed: D28.A, R139.1
unnamed: JP82.1, R139.2
unnamed: JP84.3, R136.2
unnamed: JP84.1, R137.2
unnamed: D29.A, R144.1
unnamed: JP85.1, R144.2
unnamed: JP87.3, R141.2
unnamed: JP87.1, R142.2
unnamed: D30.A, R149.1
unnamed: JP88.1, R149.2
unnamed: JP90.3, R146.2
unnamed: JP90.1, R147.2
unnamed: D31.A, R154.1
unnamed: JP91.1, R154.2
unnamed: JP93.3, R151.2
unnamed: JP93.1, R152.2
unnamed: D32.A, R159.1
unnamed: JP94.1, R159.2
unnamed: JP96.3, R156.2
unnamed: JP96.1, R157.2
unnamed: D33.A, R164.1
unnamed: JP97.1, R164.2
unnamed: JP99.3, R161.2
unnamed: JP99.1, R162.2
unnamed: D34.A, R169.1
unnamed: JP100.1, R169.2
unnamed: JP102.3, R166.2
unnamed: JP102.1, R167.2
unnamed: D35.A, R174.1
unnamed: JP103.1, R174.2
unnamed: JP105.3, R171.2
unnamed: JP105.1, R172.2
SCL: J1.4, J2.4, J3.4, R2.1, U1.P5
SCL1: J4.4, J5.4, J6.4, R7.1, U2.P5
SCL2: J7.4, J8.4, J9.4, R12.1, U3.P5
SCL3: J10.4, J11.4, J12.4, R17.1, U4.P5
SCL4: J13.4, J14.4, J15.4, R22.1, U5.P5
SCL5: J16.4, J17.4, J18.4, R27.1, U6.P5
SCL6: J19.4, J20.4, J21.4, R32.1, U7.P5
SCL7: J22.4, J23.4, J24.4, R37.1, U8.P5
SCL8: J25.4, J26.4, J27.4, R42.1, U9.P5
SCL9: J28.4, J29.4, J30.4, R47.1, U10.P5
SCL10: J31.4, J32.4, J33.4, R52.1, U11.P5
SCL11: J34.4, J35.4, J36.4, R57.1, U12.P5
SCL12: J37.4, J38.4, J39.4, R62.1, U13.P5
SCL13: J40.4, J41.4, J42.4, R67.1, U14.P5
SCL14: J43.4, J44.4, J45.4, R72.1, U15.P5
SCL15: J46.4, J47.4, J48.4, R77.1, U16.P5
SCL16: J49.4, J50.4, J51.4, R82.1, U17.P5
SCL17: J52.4, J53.4, J54.4, R87.1, U18.P5
SCL18: J55.4, J56.4, J57.4, R92.1, U19.P5
SCL19: J58.4, J59.4, J60.4, R97.1, U20.P5
SCL20: J61.4, J62.4, J63.4, R102.1, U21.P5
SCL21: J64.4, J65.4, J66.4, R107.1, U22.P5
SCL22: J67.4, J68.4, J69.4, R112.1, U23.P5
SCL23: J70.4, J71.4, J72.4, R117.1, U24.P5
SCL24: J73.4, J74.4, J75.4, R122.1, U25.P5
SCL25: J76.4, J77.4, J78.4, R127.1, U26.P5
SCL26: J79.4, J80.4, J81.4, R132.1, U27.P5
SCL27: J82.4, J83.4, J84.4, R137.1, U28.P5
SCL28: J85.4, J86.4, J87.4, R142.1, U29.P5
SCL29: J88.4, J89.4, J90.4, R147.1, U30.P5
SCL30: J91.4, J92.4, J93.4, R152.1, U31.P5
SCL31: J94.4, J95.4, J96.4, R157.1, U32.P5
SCL32: J97.4, J98.4, J99.4, R162.1, U33.P5
SCL33: J100.4, J101.4, J102.4, R167.1, U34.P5
SCL34: J103.4, J104.4, J105.4, R172.1, U35.P5
SDA: J1.3, J2.3, J3.3, R1.1, U1.P2
SDA1: J4.3, J5.3, J6.3, R6.1, U2.P2
SDA2: J7.3, J8.3, J9.3, R11.1, U3.P2
SDA3: J10.3, J11.3, J12.3, R16.1, U4.P2
SDA4: J13.3, J14.3, J15.3, R21.1, U5.P2
SDA5: J16.3, J17.3, J18.3, R26.1, U6.P2
SDA6: J19.3, J20.3, J21.3, R31.1, U7.P2
SDA7: J22.3, J23.3, J24.3, R36.1, U8.P2
SDA8: J25.3, J26.3, J27.3, R41.1, U9.P2
SDA9: J28.3, J29.3, J30.3, R46.1, U10.P2
SDA10: J31.3, J32.3, J33.3, R51.1, U11.P2
SDA11: J34.3, J35.3, J36.3, R56.1, U12.P2
SDA12: J37.3, J38.3, J39.3, R61.1, U13.P2
SDA13: J40.3, J41.3, J42.3, R66.1, U14.P2
SDA14: J43.3, J44.3, J45.3, R71.1, U15.P2
SDA15: J46.3, J47.3, J48.3, R76.1, U16.P2
SDA16: J49.3, J50.3, J51.3, R81.1, U17.P2
SDA17: J52.3, J53.3, J54.3, R86.1, U18.P2
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

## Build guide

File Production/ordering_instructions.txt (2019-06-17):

panel size, 143x195mm
PCB thickness, 1.6mm
number of layers, 2
soldermask color, Red
silkscreen color, White
oz copper, 1oz
finish, HASL lead free
stencils, bottom
pcs per panel, 35
min trace width, 0.203200mm / 0.008000in
min drill size, 0.381000mm / 0.015000in

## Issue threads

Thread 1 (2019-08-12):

Ambiguity in requestFrom

edspark, 2019-08-12:
### Subject of the issue
It seems that the compiler throws an ambiguous non stopping error when two uint8_t arguments are being passed to requestFrom(). Though when we look in the Wire library:
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

Hmmmm.....

edspark, 2019-08-19:
This shouldn't be filed here but in the library - derp.

Closed 2019-08-19.

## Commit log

2019-06-09 Adds initial commits, still needs:
    *10k pull up on interrupt
    *trace work
    *silk
    [SparkFun_Ambient_Light_Sensor_VEML6030.brd, SparkFun_Ambient_Light_Sensor_VEML6030.sch]
2019-06-09 Finishes tracework, adds 10k pull up resistor to interrupt pin, needs silk
    [SparkFun_Ambient_Light_Sensor_VEML6030.brd, SparkFun_Ambient_Light_Sensor_VEML6030.sch]
2019-06-10 Adds silk to board for all things needing lables, adds text to jumpers in schematic,
    [SparkFun_Ambient_Light_Sensor_VEML6030.brd, SparkFun_Ambient_Light_Sensor_VEML6030.sch]
2019-06-10 Updates polarity marker on VEML6030, adds VCC range to schematic, improves ground pour on the underside.
    [SparkFun_Ambient_Light_Sensor_VEML6030.brd, SparkFun_Ambient_Light_Sensor_VEML6030.sch]
2019-06-12 Adds application note to documentation, and updates Ambient Light Sensor with SKU
    [SparkFun_Ambient_Light_Sensor_VEML6030.brd, SparkFun_Ambient_Light_Sensor_VEML6030.sch]
2019-06-12 Routes 3.3V line on underside and data lines on the topside...
    * Adds silk on the underside for address selection
    * Adds power silk to LED
    * moves resistor to top side
    * Fixes GND net on 5 pin header
    * Changes version to v10
    [SparkFun_Ambient_Light_Sensor_VEML6030.brd, SparkFun_Ambient_Light_Sensor_VEML6030.sch]
2019-06-13 Makes small adjustment to 3.3V traces
    [SparkFun_Ambient_Light_Sensor_VEML6030.brd]
2019-06-13 Updates address silk for better clarificaiton, moves 3.3V trace to top near PTH for better ground pour
    [SparkFun_Ambient_Light_Sensor_VEML6030.brd]
2019-06-14 Clears up some minor DRC errors, reduces dimension to .008 inches
    [SparkFun_Ambient_Light_Sensor_VEML6030.brd]
2019-06-14 Deletes some wire stubs, moves vias that are able to be moved away from silk
    [SparkFun_Ambient_Light_Sensor_VEML6030.brd]
2019-06-17 Changed "Default" silk with "Open"
    [SparkFun_Ambient_Light_Sensor_VEML6030.brd]
2019-06-17 Centers SparkFun logo on the underside
    [SparkFun_Ambient_Light_Sensor_VEML6030.brd]
2019-06-17 Adds production files
    [SparkFun_Ambient_Light_Sensor_VEML6030-Panel.brd]
2019-06-17 Adds gerbers with paste layer
2019-07-12 Adds superscript to I2C

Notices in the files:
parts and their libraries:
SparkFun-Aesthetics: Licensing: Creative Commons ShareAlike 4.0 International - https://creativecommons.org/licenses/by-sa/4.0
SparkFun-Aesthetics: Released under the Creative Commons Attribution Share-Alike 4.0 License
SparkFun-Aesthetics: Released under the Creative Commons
